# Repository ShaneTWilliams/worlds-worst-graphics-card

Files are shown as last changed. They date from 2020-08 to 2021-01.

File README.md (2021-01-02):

# World's Worst Graphics Card

This board consists of an SiI1136 HDMI transmitter, driven by a dual-core 480 MHz STM32H745IIT6 microcontroller, with 64 MB of external SDRAM. It is USB-powered and uses SWD for flash and debug.

The goal of this project is to give me a custom, bare-metal platform on which I can try my hand at implementing simple graphics algorithms from scratch. The STM32 is key for this, with its dual cores, DMA2D (a DMA peripheral designed to fill frame buffers very quickly) and its LTDC peripheral, which will drive the display without any CPU load.







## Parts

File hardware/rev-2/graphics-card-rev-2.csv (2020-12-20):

Id | Designator | Package | Quantity | Designation | Supplier and ref
1 | U6 | LQFP-176_24x24mm_P0.5mm | 1 | STM32H745IITx
2 | U5 | TQFP-100-1EP_14x14mm_P0.5mm_EP5x5mm | 1 | SiI1136
3 | CSCL | TestPoint_Pad_D1.0mm | 1 | CSCL
4 | CSDA | TestPoint_Pad_D1.0mm | 1 | CSDA
5 | C2,C13,C57,C58,C59,C60 | C_0805_2012Metric_Pad1.15x1.40mm_HandSolder | 6 | 4.7u
6 | C3,C4,C5,C6,C7,C8,C9,C10,C11,C12,C28,C29,C30,C31,C32,C33,C34,C35,C36,C37,C49,C51,C21,C23,C24,C25,C26,C27,C14,C15,C16,C17,C18,C19,C20,C38,C40,C41,C42,C43,C44,C46,C47,C55,C65,C66,C67,C63,C64 | C_0805_2012Metric_Pad1.15x1.40mm_HandSolder | 49 | 100n
7 | C1,C48,C50 | C_0805_2012Metric_Pad1.15x1.40mm_HandSolder | 3 | 1u
8 | C52,C53,C54 | C_0805_2012Metric_Pad1.15x1.40mm_HandSolder | 3 | 2.2u
9 | C22,C39,C45 | C_0805_2012Metric_Pad1.15x1.40mm_HandSolder | 3 | 10u
10 | C56 | C_0805_2012Metric_Pad1.15x1.40mm_HandSolder | 1 | 22u
11 | C61,C62 | C_0805_2012Metric_Pad1.15x1.40mm_HandSolder | 2 | 10p
12 | D1 | LED_0805_2012Metric_Pad1.15x1.40mm_HandSolder | 1 | 5V_LED
13 | D2 | LED_0805_2012Metric_Pad1.15x1.40mm_HandSolder | 1 | 3V3_LED
14 | D7 | LED_0805_2012Metric_Pad1.15x1.40mm_HandSolder | 1 | 1V2_LED
15 | D3 | LED_0805_2012Metric_Pad1.15x1.40mm_HandSolder | 1 | LED_IND0
16 | D4 | LED_0805_2012Metric_Pad1.15x1.40mm_HandSolder | 1 | LED_IND1
17 | D5 | LED_0805_2012Metric_Pad1.15x1.40mm_HandSolder | 1 | LED_IND2
18 | D6 | LED_0805_2012Metric_Pad1.15x1.40mm_HandSolder | 1 | LED_OK
19 | D8 | LED_0805_2012Metric_Pad1.15x1.40mm_HandSolder | 1 | LED_WARN
20 | D9 | LED_0805_2012Metric_Pad1.15x1.40mm_HandSolder | 1 | LED_ERR
21 | FB1,FB2,FB3 | R_0805_2012Metric_Pad1.15x1.40mm_HandSolder | 3 | 1k@100MHz
22 | J1,J2 | USB_Micro-B_Amphenol_10103594-0001LF_Horizontal | 2 | USB_B_Micro
23 | J3 | AMPHENOL_10029449-001RLF | 1 | HDMI_A
24 | L1 | L_0805_2012Metric_Pad1.15x1.40mm_HandSolder | 1 | 4.7u
25 | R1 | R_0805_2012Metric_Pad1.15x1.40mm_HandSolder | 1 | 510
26 | R2,R20,R19 | R_0805_2012Metric_Pad1.15x1.40mm_HandSolder | 3 | 10k
27 | R7,R15 | R_0805_2012Metric_Pad1.15x1.40mm_HandSolder | 2 | 330
28 | R3,R4,R6 | R_0805_2012Metric_Pad1.15x1.40mm_HandSolder | 3 | 4.7K
29 | R5 | R_0805_2012Metric_Pad1.15x1.40mm_HandSolder | 1 | 27k
30 | R8,R9 | R_0805_2012Metric_Pad1.15x1.40mm_HandSolder | 2 | 2k
31 | R10,R11,R12,R13,R14,R16 | R_0805_2012Metric_Pad1.15x1.40mm_HandSolder | 6 | 680
32 | R18 | R_0805_2012Metric_Pad1.15x1.40mm_HandSolder | 1 | 4.06k
33 | R17 | R_0805_2012Metric_Pad1.15x1.40mm_HandSolder | 1 | 400
34 | D+ | TestPoint_Pad_D1.0mm | 1 | USB_D+
35 | D- | TestPoint_Pad_D1.0mm | 1 | USB_D-
36 | +5 | TestPoint_Pad_D1.0mm | 1 | +5V
37 | VSYNC | TestPoint_Pad_D1.0mm | 1 | VSYNC
38 | +33 | TestPoint_Pad_D1.0mm | 1 | +3V3
39 | +12 | TestPoint_Pad_D1.0mm | 1 | +1V2
40 | CEC | TestPoint_Pad_D1.0mm | 1 | CEC
41 | DSCL | TestPoint_Pad_D1.0mm | 1 | DSCL
42 | DSDA | TestPoint_Pad_D1.0mm | 1 | DSDA
43 | HSYNC | TestPoint_Pad_D1.0mm | 1 | HSYNC
44 | IDCK | TestPoint_Pad_D1.0mm | 1 | IDCK
45 | DE | TestPoint_Pad_D1.0mm | 1 | DE
46 | U2 | SOT-23-5 | 1 | TPS613222ADBVR
47 | U3 | SOT-223-3_TabPin2 | 1 | ZLDO1117G33TA
48 | U1 | TSOP-II-54_22.2x10.16mm_P0.8mm | 1 | IS42S16400J-7TL
49 | U4 | SOT-223-3_TabPin2 | 1 | ZLDO1117G12TA
50 | Y1 | Crystal_SMD_5032-2Pin_5.0x3.2mm_HandSoldering | 1 | 40MHZ/8PF
51 | SW1,SW2 | PTS645SM43SMTR92_Switch | 2 | RESET
52 | J4 | PinHeader_2x03_P2.54mm_Vertical_SMD | 1 | Conn_02x03_Odd_Even
53 | +VIN | TestPoint_Pad_D1.0mm | 1 | USB_VIN
54 | Q1 | SOT-23 | 1 | ZXMN2A01F
55 | R21 | R_0805_2012Metric_Pad1.15x1.40mm_HandSolder | 1 | 100
56 | R22 | R_0805_2012Metric_Pad1.15x1.40mm_HandSolder | 1 | 1M

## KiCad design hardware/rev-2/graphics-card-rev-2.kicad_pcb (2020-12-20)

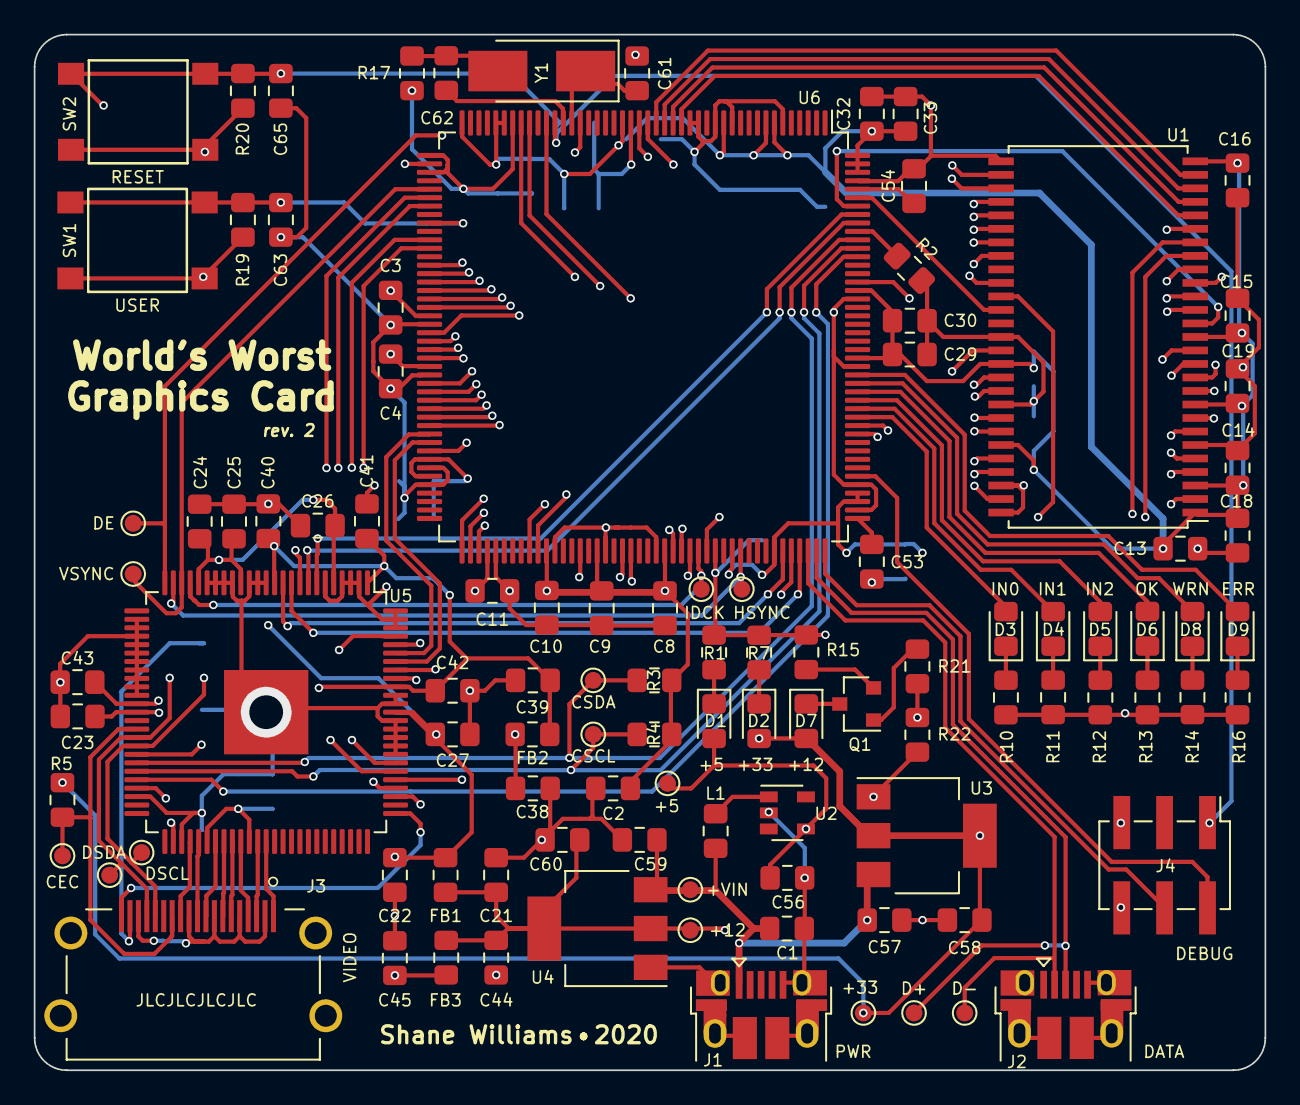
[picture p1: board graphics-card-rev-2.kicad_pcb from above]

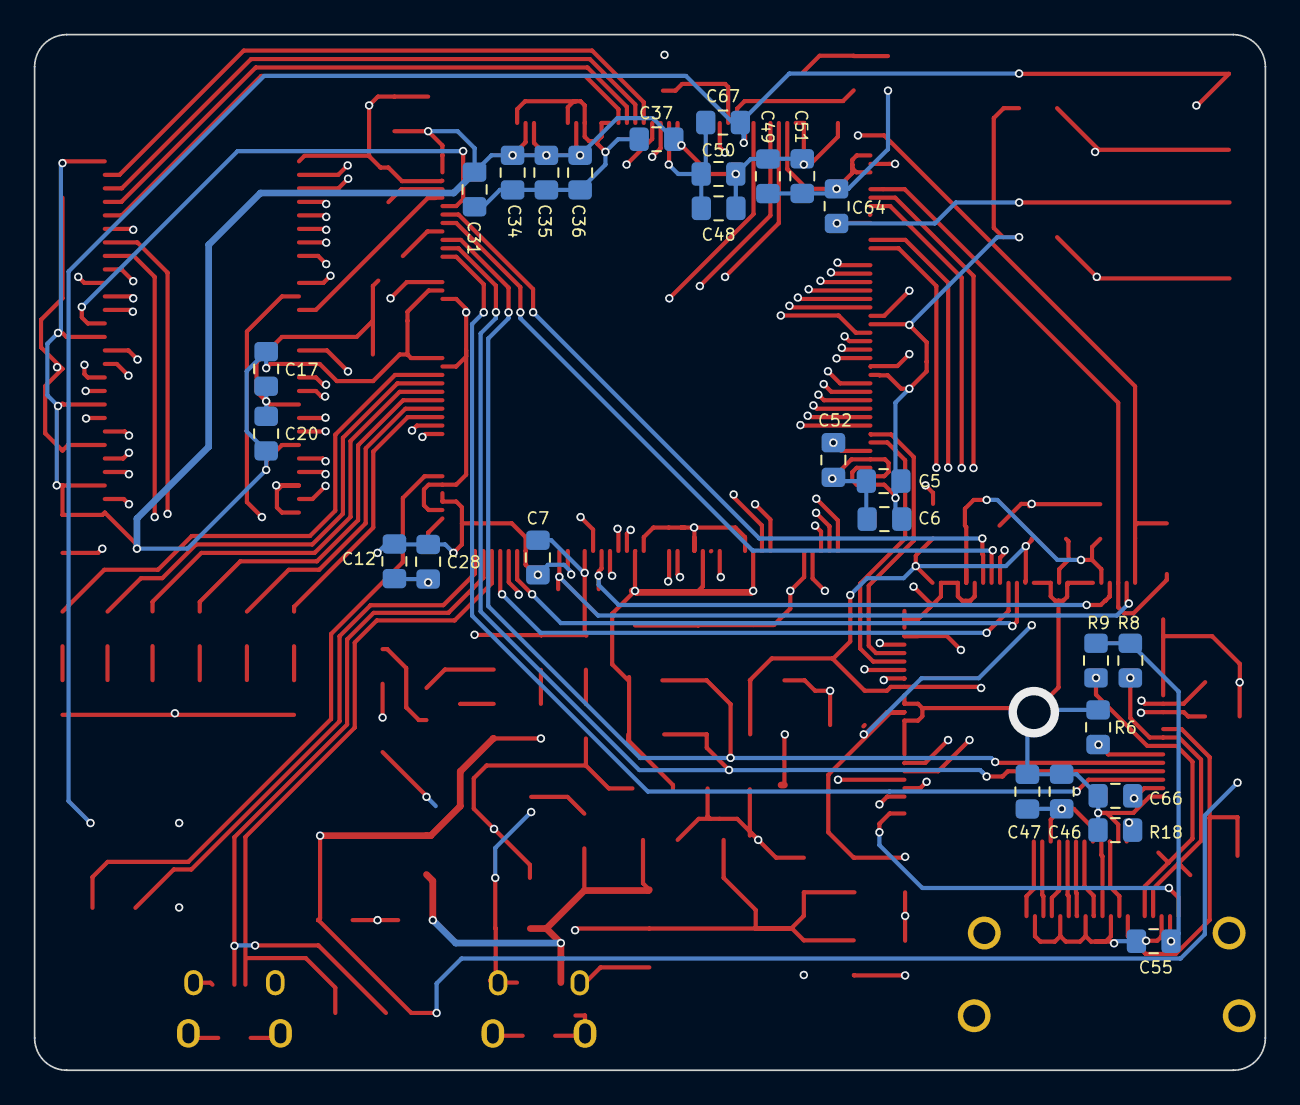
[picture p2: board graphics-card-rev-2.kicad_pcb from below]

Board: 4 copper layers, 72.9 x 61.3 mm, 131 parts (27 on the bottom side), 114 nets.

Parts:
+5: +5V; TestPoint_Pad_D1.0mm
+12: +1V2; TestPoint_Pad_D1.0mm
+33: +3V3; TestPoint_Pad_D1.0mm
+VIN: USB_VIN; TestPoint_Pad_D1.0mm
C1, C48, C50: 1u; C_0805_2012Metric_Pad1.15x1.40mm_HandSolder
C2, C13, C57, C58, C59, C60: 4.7u; C_0805_2012Metric_Pad1.15x1.40mm_HandSolder
C3, C4, C5, C6, C7, C8, C9, C10, C11, C12, C14, C15, C16, C17, C18, C19, C20, C21, C23, C24, C25, C26, C27, C28, C29, C30, C31, C32, C33, C34, C35, C36, C37, C38, C40, C41, C42, C43, C44, C46, C47, C49, C51, C55, C63, C64, C65, C66, C67: 100n; C_0805_2012Metric_Pad1.15x1.40mm_HandSolder
C22, C39, C45: 10u; C_0805_2012Metric_Pad1.15x1.40mm_HandSolder
C52, C53, C54: 2.2u; C_0805_2012Metric_Pad1.15x1.40mm_HandSolder
C56: 22u; C_0805_2012Metric_Pad1.15x1.40mm_HandSolder
C61, C62: 10p; C_0805_2012Metric_Pad1.15x1.40mm_HandSolder
CEC: CEC; TestPoint_Pad_D1.0mm
CSCL: CSCL; TestPoint_Pad_D1.0mm
CSDA: CSDA; TestPoint_Pad_D1.0mm
D1: 5V_LED; LED_0805_2012Metric_Pad1.15x1.40mm_HandSolder
D2: 3V3_LED; LED_0805_2012Metric_Pad1.15x1.40mm_HandSolder
D3: LED_IND0; LED_0805_2012Metric_Pad1.15x1.40mm_HandSolder
D4: LED_IND1; LED_0805_2012Metric_Pad1.15x1.40mm_HandSolder
D5: LED_IND2; LED_0805_2012Metric_Pad1.15x1.40mm_HandSolder
D6: LED_OK; LED_0805_2012Metric_Pad1.15x1.40mm_HandSolder
D7: 1V2_LED; LED_0805_2012Metric_Pad1.15x1.40mm_HandSolder
D8: LED_WARN; LED_0805_2012Metric_Pad1.15x1.40mm_HandSolder
D9: LED_ERR; LED_0805_2012Metric_Pad1.15x1.40mm_HandSolder
D+: USB_D+; TestPoint_Pad_D1.0mm
D-: USB_D-; TestPoint_Pad_D1.0mm
DE: DE; TestPoint_Pad_D1.0mm
DSCL: DSCL; TestPoint_Pad_D1.0mm
DSDA: DSDA; TestPoint_Pad_D1.0mm
FB1, FB2, FB3: 1k@100MHz; R_0805_2012Metric_Pad1.15x1.40mm_HandSolder
HSYNC: HSYNC; TestPoint_Pad_D1.0mm
IDCK: IDCK; TestPoint_Pad_D1.0mm
J1, J2: USB_B_Micro; USB_Micro-B_Amphenol_10103594-0001LF_Horizontal
J3: HDMI_A; AMPHENOL_10029449-001RLF
J4: Conn_02x03_Odd_Even; PinHeader_2x03_P2.54mm_Vertical_SMD
L1: 4.7u; L_0805_2012Metric_Pad1.15x1.40mm_HandSolder
Q1: ZXMN2A01F; SOT-23
R1: 510; R_0805_2012Metric_Pad1.15x1.40mm_HandSolder
R2, R19, R20: 10k; R_0805_2012Metric_Pad1.15x1.40mm_HandSolder
R3, R4, R6: 4.7K; R_0805_2012Metric_Pad1.15x1.40mm_HandSolder
R5: 27k; R_0805_2012Metric_Pad1.15x1.40mm_HandSolder
R7, R15: 330; R_0805_2012Metric_Pad1.15x1.40mm_HandSolder
R8, R9: 2k; R_0805_2012Metric_Pad1.15x1.40mm_HandSolder
R10, R11, R12, R13, R14, R16: 680; R_0805_2012Metric_Pad1.15x1.40mm_HandSolder
R17: 400; R_0805_2012Metric_Pad1.15x1.40mm_HandSolder
R18: 4.06k; R_0805_2012Metric_Pad1.15x1.40mm_HandSolder
R21: 100; R_0805_2012Metric_Pad1.15x1.40mm_HandSolder
R22: 1M; R_0805_2012Metric_Pad1.15x1.40mm_HandSolder
SW1, SW2: RESET; PTS645SM43SMTR92_Switch
U1: IS42S16400J-7TL; TSOP-II-54_22.2x10.16mm_P0.8mm
U2: TPS613222ADBVR; SOT-23-5
U3: ZLDO1117G33TA; SOT-223-3_TabPin2
U4: ZLDO1117G12TA; SOT-223-3_TabPin2
U5: SiI1136; TQFP-100-1EP_14x14mm_P0.5mm_EP5x5mm
U6: STM32H745IITx; LQFP-176_24x24mm_P0.5mm
VSYNC: VSYNC; TestPoint_Pad_D1.0mm
Y1: 40MHZ/8PF; Crystal_SMD_5032-2Pin_5.0x3.2mm_HandSoldering

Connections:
+1V2: +12.1, C21.1, C44.1, C60.1, FB1.2, FB3.2, R21.2, R22.1, U4.2
+3V3: +33.1, C2.1, C3.1, C4.1, C5.1, C6.1, C7.1, C8.1, C9.1, C10.1, C11.1, C12.1, C13.1, C14.1, C15.1, C16.1, C17.1, C18.1, C19.1, C20.1, C28.1, C29.1, C30.1, C31.1, C32.1, C33.1, C34.1, C35.1, C36.1, C37.1, C38.1, C48.1, C49.1, C50.1, C51.1, C58.1, D2.2, D7.2, FB2.2, R3.1, R4.1, R5.1, R19.1, R20.1, U1.1, U1.3, U1.9, U1.14, U1.27, U1.43, U1.49, U3.2, U6.7, U6.8, U6.13, U6.25, U6.39, U6.40, U6.44, U6.65, U6.71, U6.82, U6.84, U6.92, U6.99, U6.105, U6.113, U6.121, U6.126, U6.135, U6.136, U6.152, U6.160, U6.174, U6.175, U6.176
+5V: +5.1, C55.1, C56.1, D1.2, J3.18, R8.1, R9.1, U2.4
/AVCC_SII: C45.1, C46.1, C47.1, FB3.1, U5.56, U5.61
/B_CB_3: U5.11, U6.127
/B_CB_4: U5.10, U6.129
/B_CB_5: U5.9, U6.46
/B_CB_6: U5.8, U6.168
/B_CB_7: U5.7, U6.169
/CEC: CEC.1, J3.13, R5.2, U5.40
/CSCL: CSCL.1, R4.2, U5.45, U6.165
/CSDA: CSDA.1, R3.2, U5.44, U6.166
/CVCC12_SII: C22.1, C23.1, C24.1, C25.1, C26.1, C27.1, FB1.1, U5.5, U5.16, U5.21, U5.38, U5.88
/DE: DE.1, U5.25, U6.30
/DSCL: DSCL.1, J3.15, R9.2, U5.42
/DSDA: DSDA.1, J3.16, R8.2, U5.41
/G_Y_2: U5.97, U6.51
/G_Y_3: U5.96, U6.103
/G_Y_4: U5.95, U6.78
/G_Y_5: U5.94, U6.79
/G_Y_6: U5.93, U6.108
/G_Y_7: U5.92, U6.109
/HPD: J3.19, U5.76
/HSYNC: HSYNC.1, U5.24, U6.122
/IDCK: IDCK.1, U5.22, U6.117
/INT_SII: U5.46, U6.164
/IOVCC_SII: C39.1, C40.1, C41.1, C42.1, C43.1, FB2.1, U5.1, U5.12, U5.37, U5.91
/LED_ERR: D9.2, U6.150
/LED_IND0: D3.2, U6.145
/LED_IND1: D4.2, U6.146
/LED_IND2: D5.2, U6.147
/LED_OK: D6.2, U6.148
/LED_WARN: D8.2, U6.149
/OSC_IN: C61.1, U6.31, Y1.1
/OSC_OUT: R17.1, U6.32
/RAM_A0: U1.23, U6.18
/RAM_A1: U1.24, U6.19
/RAM_A2: U1.25, U6.20
/RAM_A3: U1.26, U6.21
/RAM_A4: U1.29, U6.22
/RAM_A5: U1.30, U6.23
/RAM_A6: U1.31, U6.59
/RAM_A7: U1.32, U6.60
/RAM_A8: U1.33, U6.61
/RAM_A9: U1.34, U6.62
/RAM_A10: U1.22, U6.63
/RAM_A11: U1.35, U6.66
/RAM_BA0: U1.20, U6.114
/RAM_BA1: U1.21, U6.115
/RAM_CKE: U1.37, U6.37
/RAM_CLK: U1.38, U6.118
/RAM_D0: U1.2, U6.97
/RAM_D1: U1.4, U6.98
/RAM_D2: U1.5, U6.143
/RAM_D3: U1.7, U6.144
/RAM_D4: U1.8, U6.67
/RAM_D5: U1.10, U6.68
/RAM_D6: U1.11, U6.69
/RAM_D7: U1.13, U6.72
/RAM_D8: U1.42, U6.73
/RAM_D9: U1.44, U6.74
/RAM_D10: U1.45, U6.75
/RAM_D11: U1.47, U6.76
/RAM_D12: U1.48, U6.77
/RAM_D13: U1.50, U6.89
/RAM_D14: U1.51, U6.90
/RAM_D15: U1.53, U6.91
/RAM_NBL0: U1.15, U6.170
/RAM_NBL1: U1.39, U6.171
/R_CR_3: U5.82, U6.55
/R_CR_4: U5.81, U6.50
/R_CR_5: U5.80, U6.128
/R_CR_6: U5.79, U6.56
/R_CR_7: U5.78, U6.116
/SWCLK: J4.2, U6.138
/SWDIO: J4.4, U6.132
/TMDS_CLK+: J3.10, U5.55
/TMDS_CLK-: J3.12, U5.54
/TMDS_D0+: J3.7, U5.58
/TMDS_D0-: J3.9, U5.57
/TMDS_D1+: J3.4, U5.60
/TMDS_D1-: J3.6, U5.59
/TMDS_D2+: J3.1, U5.63
/TMDS_D2-: J3.3, U5.62
/USB_D+: D+.1, J2.3, U6.131
/USB_D-: D-.1, J2.2, U6.130
/USB_VIN: +VIN.1, C1.1, C57.1, C59.1, J1.1, L1.1, U3.3, U4.3
/VSYNC: U5.23, U6.49, VSYNC.1
/~RAM_CAS: U1.17, U6.161
/~RAM_CS: U1.19, U6.36
/~RAM_RAS: U1.18, U6.58
/~RAM_WE: U1.16, U6.34
/~RESET: C65.1, C66.1, C67.1, J4.1, R20.2, SW2.1, U5.47, U6.33
/~USR_BTN: C63.1, C64.1, R19.2, SW1.1, U6.53
GND: C1.2, C2.2, C3.2, C4.2, C5.2, C6.2, C7.2, C8.2, C9.2, C10.2, C11.2, C12.2, C13.2, C14.2, C15.2, C16.2, C17.2, C18.2, C19.2, C20.2, C21.2, C22.2, C23.2, C24.2, C25.2, C26.2, C27.2, C28.2, C29.2, C30.2, C31.2, C32.2, C33.2, C34.2, C35.2, C36.2, C37.2, C38.2, C39.2, C40.2, C41.2, C42.2, C43.2, C44.2, C45.2, C46.2, C47.2, C48.2, C49.2, C50.2, C51.2, C52.2, C53.2, C54.2, C55.2, C56.2, C57.2, C58.2, C59.2, C60.2, C61.2, C62.2, C63.2, C64.2, C65.2, C66.2, C67.2, J1.5, J1.6, J2.5, J2.6, J3.2, J3.5, J3.8, J3.11, J3.17, J3.SH, J4.5, J4.6, R1.2, R2.2, R6.2, R7.2, R10.1, R11.1, R12.1, R13.1, R14.1, R15.2, R16.1, R18.2, R22.2, SW1.2, SW2.2, U1.6, U1.12, U1.28, U1.41, U1.46, U1.52, U1.54, U2.2, U3.1, U4.1, U5.2, U5.3, U5.4, U5.6, U5.13, U5.14, U5.15, U5.17, U5.18, U5.19, U5.20, U5.27, U5.28, U5.29, U5.30, U5.31, U5.32, U5.33, U5.34, U5.35, U5.36, U5.48, U5.53, U5.83, U5.84, U5.85, U5.86, U5.87, U5.89, U5.90, U5.98, U5.99, U5.100, U5.101, U6.6, U6.12, U6.14, U6.16, U6.17, U6.24, U6.38, U6.45, U6.47, U6.64, U6.70, U6.81, U6.83, U6.93, U6.100, U6.106, U6.112, U6.119, U6.134, U6.137, U6.151, U6.159, U6.173
unnamed: C52.1, U6.80
unnamed: C53.1, U6.133
unnamed: C54.1, U6.172
unnamed: C62.1, R17.2, Y1.2
unnamed: D1.1, R1.1
unnamed: D2.1, R7.1
unnamed: D3.1, R10.2
unnamed: D4.1, R11.2
unnamed: D5.1, R12.2
unnamed: D6.1, R13.2
unnamed: D7.1, Q1.3
unnamed: D8.1, R14.2
unnamed: D9.1, R16.2
unnamed: L1.2, U2.1
unnamed: Q1.1, R21.1
unnamed: Q1.2, R15.1
unnamed: R2.1, U6.167
unnamed: R6.1, U5.43
unnamed: R18.1, U5.52

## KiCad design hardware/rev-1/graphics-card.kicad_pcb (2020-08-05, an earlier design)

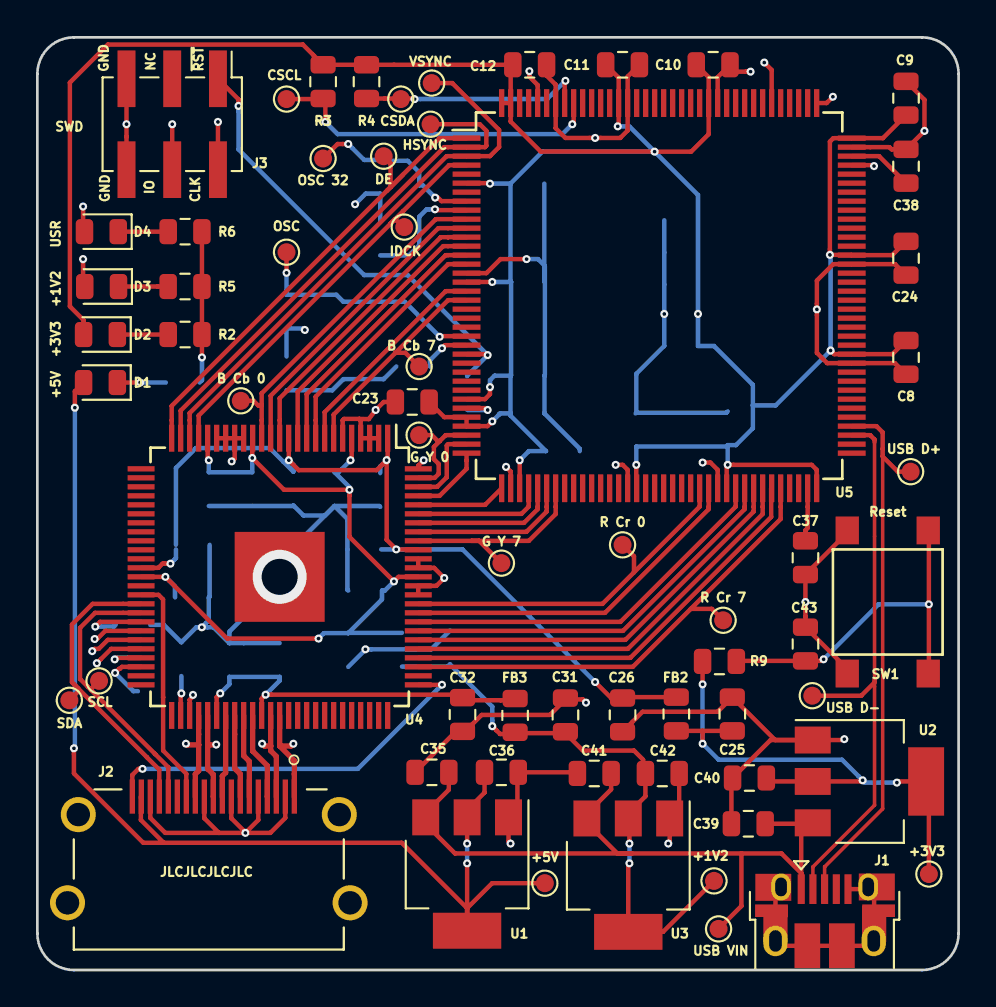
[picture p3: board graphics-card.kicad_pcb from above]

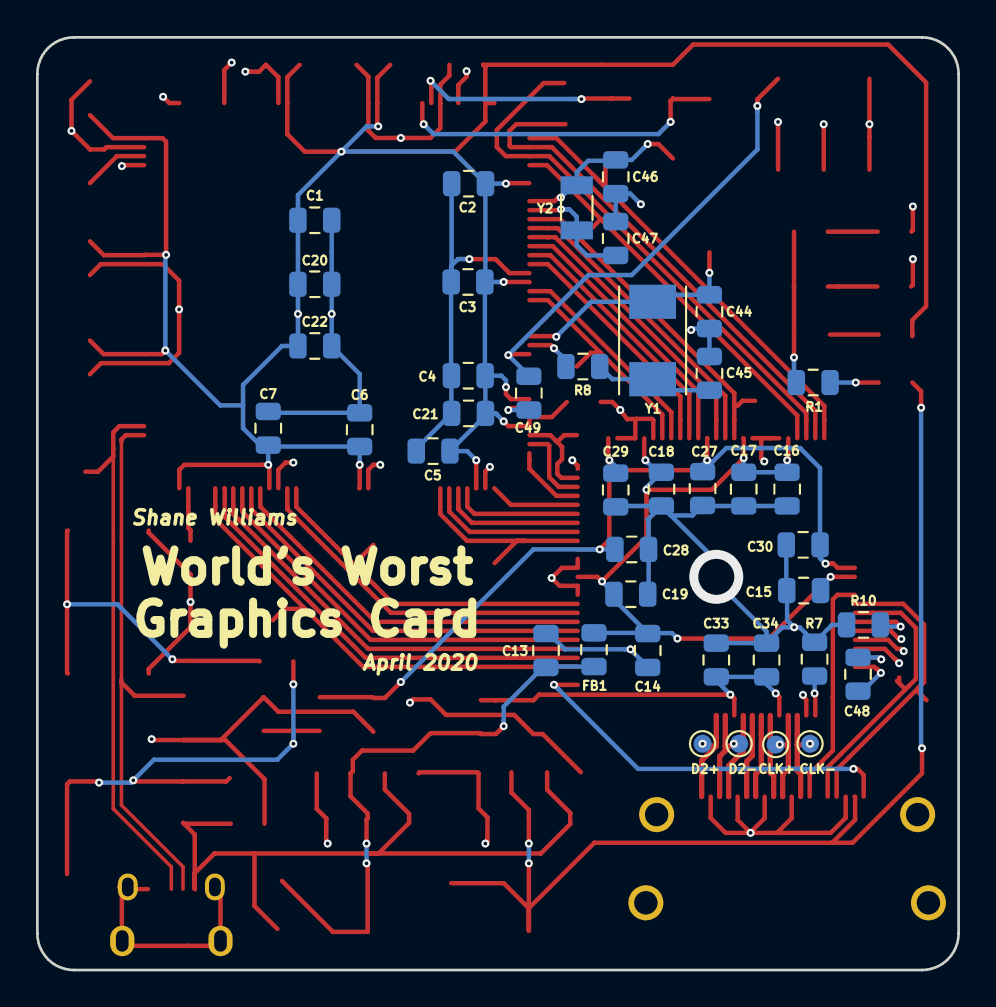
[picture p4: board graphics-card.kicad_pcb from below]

Board: 4 copper layers, 51.2 x 51.8 mm, 103 parts (40 on the bottom side), 70 nets.

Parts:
+1V2: +1V2; TestPoint_Pad_D1.0mm
+3V3: +3V3; TestPoint_Pad_D1.0mm
+5V: +5V; TestPoint_Pad_D1.0mm
B Cb 0: B_CB_0; TestPoint_Pad_D1.0mm
B Cb 7: B_CB_7; TestPoint_Pad_D1.0mm
C1: 4.7u; C_0805_2012Metric
C2, C3, C4, C5, C6, C7, C8, C9, C10, C11, C12, C13, C15, C16, C17, C18, C19, C21, C23, C24, C25, C27, C28, C29, C30, C31, C33, C34, C37, C38, C43, C48, C49: 100n; C_0805_2012Metric
C14, C26, C32: 10u; C_0805_2012Metric
C20, C22, C35, C36, C39, C40, C41, C42: 1u; C_0805_2012Metric
C44, C45: 27p; C_0805_2012Metric
C46, C47: 15p; C_0805_2012Metric
CLK+: CLK+; TestPoint_Pad_D1.0mm
CLK-: CLK-; TestPoint_Pad_D1.0mm
CSCL: CSCL; TestPoint_Pad_D1.0mm
CSDA: CSDA; TestPoint_Pad_D1.0mm
D1: 5V Rail LED; LED_0805_2012Metric
D2: 3.3V Rail LED; LED_0805_2012Metric
D2+: D2+; TestPoint_Pad_D1.0mm
D2-: D2-; TestPoint_Pad_D1.0mm
D3: 1.2V Rail LED; LED_0805_2012Metric
D4: USR_LED; LED_0805_2012Metric
DE: DE; TestPoint_Pad_D1.0mm
FB1, FB2, FB3: 1k@100MHz; R_0805_2012Metric
G Y 0: G_Y_0; TestPoint_Pad_D1.0mm
G Y 7: G_Y_7; TestPoint_Pad_D1.0mm
HSYNC: HSYNC; TestPoint_Pad_D1.0mm
IDCK: IDCK; TestPoint_Pad_D1.0mm
J1: USB_B_Micro; USB_Micro-B_Amphenol_10103594-0001LF_Horizontal
J2: HDMI_A_1.4; AMPHENOL_10029449-001RLF
J3: Conn_02x03_Odd_Even; PinHeader_2x03_P2.54mm_Vertical_SMD
OSC: OSC_IN; TestPoint_Pad_D1.0mm
OSC 32: OSC32_IN; TestPoint_Pad_D1.0mm
R1: 510; R_0805_2012Metric
R2: 330; R_0805_2012Metric
R3, R4, R10: 4.7k; R_0805_2012Metric
R5: 120; R_0805_2012Metric
R6: 680; R_0805_2012Metric
R7: 4.06k; R_0805_2012Metric
R8: 240; R_0805_2012Metric
R9: 10k; R_0805_2012Metric
R Cr 0: R_CR_0; TestPoint_Pad_D1.0mm
R Cr 7: R_CR_7; TestPoint_Pad_D1.0mm
SCL: SCL; TestPoint_Pad_D1.0mm
SDA: SDA; TestPoint_Pad_D1.0mm
SW1: Push Switch; PTS645SM43SMTR92_Switch
U1: AZ1117-5.0; SOT-223-3_TabPin2
U2: AZ1117-3.3; SOT-223-3_TabPin2
U3: AZ1117-1.2; SOT-223-3_TabPin2
U4: SiI1136; TQFP-100-1EP_14x14mm_P0.5mm_EP5x5mm
U5: STM32H753ZITx; LQFP-144_20x20mm_P0.5mm
USB D+: USB1_D+; TestPoint_Pad_D1.0mm
USB D-: USB1_D-; TestPoint_Pad_D1.0mm
USB VIN: USB_VIN; TestPoint_Pad_D1.0mm
VSYNC: VSYNC; TestPoint_Pad_D1.0mm
Y1: OSC; Crystal_SMD_Abracon_ABM7-2Pin_6.0x3.5mm
Y2: OSC_32; Crystal_SMD_3215-2Pin_3.2x1.5mm

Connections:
+1V2: +1V2.1, C13.1, C31.1, C42.1, D3.2, FB1.2, FB3.2, U3.2
+3V3: +3V3.1, C1.1, C2.1, C3.1, C4.1, C5.1, C6.1, C7.1, C8.1, C9.1, C10.1, C11.1, C12.1, C20.1, C21.1, C22.1, C23.1, C24.1, C25.1, C40.1, D2.2, FB2.2, R3.1, R4.1, R9.1, U2.2, U5.6, U5.17, U5.30, U5.32, U5.33, U5.39, U5.52, U5.62, U5.72, U5.84, U5.95, U5.108, U5.121, U5.131, U5.143, U5.144
+5V: +5V.1, C36.1, D1.2, J2.18, U1.2
/AVCC_SII: C32.1, C33.1, C34.1, FB3.1, U4.56, U4.61
/B_CB_0: B Cb 0.1, U4.15, U5.10
/B_CB_1: U4.14, U5.11
/B_CB_2: U4.13, U5.12
/B_CB_3: U4.11, U5.13
/B_CB_4: U4.10, U5.14
/B_CB_5: U4.9, U5.15
/B_CB_6: U4.8, U5.18
/B_CB_7: B Cb 7.1, U4.7, U5.19
/CEC: J2.13, U4.40
/CI2CA: R10.2, U4.43
/CLK+: CLK+.1, J2.10, U4.55
/CLK-: CLK-.1, J2.12, U4.54
/CSCL: CSCL.1, R3.2, U4.45, U5.136
/CSDA: CSDA.1, R4.2, U4.44, U5.137
/CVCC12_SII: C14.1, C15.1, C16.1, C17.1, C18.1, C19.1, FB1.1, U4.5, U4.16, U4.21, U4.38, U4.88
/D0+: J2.7, U4.58
/D0-: J2.9, U4.57
/D1+: J2.4, U4.60
/D1-: J2.6, U4.59
/D2+: D2+.1, J2.1, U4.63
/D2-: D2-.1, J2.3, U4.62
/DE: DE.1, U4.25, U5.1
/G_Y_0: G Y 0.1, U4.99, U5.34
/G_Y_1: U4.98, U5.35
/G_Y_2: U4.97, U5.36
/G_Y_3: U4.96, U5.37
/G_Y_4: U4.95, U5.40
/G_Y_5: U4.94, U5.41
/G_Y_6: U4.93, U5.42
/G_Y_7: G Y 7.1, U4.92, U5.43
/HPD: J2.19, U4.76
/HSYNC: HSYNC.1, U4.24, U5.2
/IDCK: IDCK.1, U4.22, U5.4
/INT_SII: U4.46, U5.140
/IOVCC_SII: C26.1, C27.1, C28.1, C29.1, C30.1, FB2.1, U4.1, U4.12, U4.37, U4.91
/OSC32_IN: C46.1, OSC 32.1, U5.8, Y2.1
/OSC32_OUT: C47.1, U5.9, Y2.2
/OSC_IN: C44.1, OSC.1, U5.23, Y1.1
/OSC_OUT: R8.2, U5.24
/R_CR_0: R Cr 0.1, U4.85, U5.59
/R_CR_1: U4.84, U5.60
/R_CR_2: U4.83, U5.63
/R_CR_3: U4.82, U5.64
/R_CR_4: U4.81, U5.65
/R_CR_5: U4.80, U5.66
/R_CR_6: U4.79, U5.67
/R_CR_7: R Cr 7.1, U4.78, U5.68
/SCL: J2.15, SCL.1, U4.42
/SDA: J2.16, SDA.1, U4.41
/SWCLK: J3.2, U5.109
/SWDIO: J3.4, U5.105
/USB1_D+: J1.3, U5.76, USB D+.1
/USB1_D-: J1.2, U5.75, USB D-.1
/USB_VIN: C35.1, C39.1, C41.1, J1.1, U1.3, U2.3, U3.3, USB VIN.1
/VSYNC: U4.23, U5.3, VSYNC.1
/~RESET: C43.1, C48.1, C49.1, J3.1, R9.2, SW1.2, U4.47, U5.25
GND: C1.2, C2.2, C3.2, C4.2, C5.2, C6.2, C7.2, C8.2, C9.2, C10.2, C11.2, C12.2, C13.2, C14.2, C15.2, C16.2, C17.2, C18.2, C19.2, C20.2, C21.2, C22.2, C23.2, C24.2, C25.2, C26.2, C27.2, C28.2, C29.2, C30.2, C31.2, C32.2, C33.2, C34.2, C35.2, C36.2, C37.2, C38.2, C39.2, C40.2, C41.2, C42.2, C43.2, C44.2, C45.2, C46.2, C47.2, C48.2, C49.2, J1.5, J1.6, J2.2, J2.5, J2.8, J2.11, J2.17, J2.SH, J3.5, J3.6, R1.2, R2.2, R5.2, R6.1, R7.2, R10.1, SW1.1, U1.1, U2.1, U3.1, U4.2, U4.3, U4.4, U4.6, U4.17, U4.18, U4.19, U4.20, U4.48, U4.53, U4.86, U4.87, U4.89, U4.90, U4.100, U4.101, U5.16, U5.31, U5.38, U5.51, U5.61, U5.83, U5.94, U5.107, U5.120, U5.130, U5.138
unnamed: C37.1, U5.71
unnamed: C38.1, U5.106
unnamed: C45.1, R8.1, Y1.2
unnamed: D1.1, R1.1
unnamed: D2.1, R2.1
unnamed: D3.1, R5.1
unnamed: D4.1, R6.2
unnamed: D4.2, U5.114
unnamed: R7.1, U4.52

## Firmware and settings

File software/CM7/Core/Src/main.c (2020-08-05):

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
/* Includes ------------------------------------------------------------------*/
#include "main.h"

/* USER CODE BEGIN PD */

#define HSEM_ID_0 (0U) /* HW semaphore 0*/
/* USER CODE END PD */


void SystemClock_Config(void);
/**
  * @brief  The application entry point.
  * @retval int
  */
int main(void)
{
/* USER CODE BEGIN Boot_Mode_Sequence_0 */
  int32_t timeout;
/* USER CODE END Boot_Mode_Sequence_0 */

/* USER CODE BEGIN Boot_Mode_Sequence_1 */
  /* Wait until CPU2 boots and enters in stop mode or timeout*/
  timeout = 0xFFFF;
  while((__HAL_RCC_GET_FLAG(RCC_FLAG_D2CKRDY) != RESET) && (timeout-- > 0));
  if ( timeout < 0 )
  {
  Error_Handler();
  }
/* USER CODE END Boot_Mode_Sequence_1 */
  /* MCU Configuration--------------------------------------------------------*/

  /* Reset of all peripherals, Initializes the Flash interface and the Systick. */
  HAL_Init();

  /* Configure the system clock */
  SystemClock_Config();
/* USER CODE BEGIN Boot_Mode_Sequence_2 */
/* When system initialization is finished, Cortex-M7 will release Cortex-M4 by means of
HSEM notification */
/*HW semaphore Clock enable*/
__HAL_RCC_HSEM_CLK_ENABLE();
/*Take HSEM */
HAL_HSEM_FastTake(HSEM_ID_0);
/*Release HSEM in order to notify the CPU2(CM4)*/
HAL_HSEM_Release(HSEM_ID_0,0);
/* wait until CPU2 wakes up from stop mode */
timeout = 0xFFFF;
while((__HAL_RCC_GET_FLAG(RCC_FLAG_D2CKRDY) == RESET) && (timeout-- > 0));
if ( timeout < 0 )
{
Error_Handler();
}
/* USER CODE END Boot_Mode_Sequence_2 */

  /* Initialize all configured peripherals */
  /* Infinite loop */
  /* USER CODE BEGIN WHILE */
  while (1)
  {
    /* USER CODE END WHILE */

    /* USER CODE BEGIN 3 */
  }
  /* USER CODE END 3 */
}

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


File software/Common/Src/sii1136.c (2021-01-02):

#include "sii1136.h"

// I2C Statuses.
typedef enum {
	SII1136_I2C_STATUS_OK = 0x00,
	SII1136_I2C_STATUS_ERROR = 0x01,
	SII1136_I2C_STATUS_BUSY = 0x02,
	SII1136_I2C_STATUS_TIMEOUT = 0x03
} sii1136_i2c_status_t;

// SiI1136 Register Addresses.
enum {
	SII1136_REG_PXL_CLK_LSB = 0x00,
	SII1136_REG_PXL_CLK_MSB = 0x01,
	SII1136_REG_VFREQ_LSB = 0x02,
	SII1136_REG_VFREQ_MSB = 0x03,
	SII1136_REG_HORIZ_RES_LSB = 0x04,
	SII1136_REG_HORIZ_RES_MSB = 0x05,
	SII1136_REG_VERT_RES_LSB = 0x06,
	SII1136_REG_VERT_RES_MSB = 0x07,

	SII1136_REG_IN_VID_FMT = 0x08,
	SII1136_REG_IN_COLOR_FMT = 0x09,
	SII1136_REG_OUT_COLOR_FMT = 0x0A,
	SII1136_REG_YC_IN_FMT = 0x0B,

	SII1136_REG_SYS_CNTL = 0x1A,

	SII1136_REG_DEV_ID = 0x1B,
	SII1136_REG_DEV_REV_ID = 0x1C,
	SII1136_REG_TPI_REV = 0x1D,

	SII1136_REG_INT_EN = 0x3C,
	SII1136_REG_INT_STATUS = 0x3D,

	SII1136_REG_SYNC_GEN = 0x60,
	SII1136_REG_SYNC_DET = 0x61,

	SII1136_REG_DE_DLY_LSB = 0x62,
	SII1136_REG_DE_DLY_MSB = 0x63,
	SII1136_REG_DE_GEN_FLAGS = 0x63,
	SII1136_REG_DE_TOP = 0x64,
	SII1136_REG_DE_CNT_LSB = 0x66,
	SII1136_REG_DE_CNT_MSB = 0x67,
	SII1136_REG_DE_LIN_LSB = 0x68,
	SII1136_REG_DE_LIN_MSB = 0x69,
	SII1136_REG_H_RES_LSB = 0x6A,
	SII1136_REG_H_RES_MSB = 0x6B,
	SII1136_REG_V_RES_LSB = 0x6C,
	SII1136_REG_V_RES_MSB = 0x6D,

	SII1136_REG_HBIT_LSB = 0x62,
	SII1136_REG_HBIT_MSB = 0x63,
	SII1136_REG_EMB_SYNC_EN = 0x63,
	SII1136_REG_F2_OFST_LSB = 0x64,
	SII1136_REG_F2_OFST_MSB = 0x65,
	SII1136_REG_HWIDTH_LSB = 0x66,
	SII1136_REG_HWIDTH_MSB = 0x67,
	SII1136_REG_VBIT = 0x68,
	SII1136_REG_VWIDTH = 0x69,

	SII1136_REG_TPI_INIT = 0xC7
};

/********************************
 ***** I2C HELPER FUNCTIONS *****
 ********************************/

static inline sii1136_i2c_status_t sii1136_i2c_write_reg(sii1136_t* self, uint16_t mem_addr,
															uint8_t data) {
	HAL_StatusTypeDef status = HAL_I2C_Mem_Write(self->_i2c_handle, self->_i2c_addr, mem_addr, 1,
			&data, 1, self->_i2c_timeout);
	return (sii1136_i2c_status_t)status;
}

static inline sii1136_i2c_status_t sii1136_i2c_write_multi_reg(sii1136_t* self, uint16_t mem_addr,
																uint8_t* data, size_t size_b) {
	HAL_StatusTypeDef status = HAL_I2C_Mem_Write(self->_i2c_handle, self->_i2c_addr, mem_addr, 1,
			data, size_b, self->_i2c_timeout);
	return (sii1136_i2c_status_t)status;
}

static inline sii1136_i2c_status_t sii1136_i2c_read_reg(sii1136_t* self, uint16_t mem_addr,
														uint8_t* data) {
	HAL_StatusTypeDef status = HAL_I2C_Mem_Read(self->_i2c_handle, self->_i2c_addr, mem_addr, 1,
			data, 1, self->_i2c_timeout);
	return (sii1136_i2c_status_t)status;
}

static inline sii1136_i2c_status_t sii1136_i2c_read_multi_reg(sii1136_t* self, uint16_t mem_addr,
																uint8_t* data, size_t size_b) {
	HAL_StatusTypeDef status = HAL_I2C_Mem_Read(self->_i2c_handle, self->_i2c_addr, mem_addr, 1,
			data, size_b, self->_i2c_timeout);
	return (sii1136_i2c_status_t)status;
}

/****************************************
 ***** TPI INITIALIZATION FUNCTIONS *****
 ****************************************/

void sii1136_configure_i2c(sii1136_t* self, I2C_HandleTypeDef* i2c, uint8_t i2c_timeout,
							uint8_t i2c_addr) {
	self->_i2c_handle = i2c;
	self->_i2c_timeout = i2c_timeout;
	self->_i2c_addr = i2c_addr;
}

sii1136_status_t sii1136_init_tpi(sii1136_t* self) {
	sii1136_i2c_status_t status = sii1136_i2c_write_reg(self, SII1136_REG_TPI_INIT, 0x00);
	if (status == SII1136_I2C_STATUS_OK) {
		return SII1136_STATUS_OK;
	}
	return SII1136_STATUS_I2C_ERR;
}

sii1136_status_t sii1136_tpi_ready(sii1136_t* self, sii1136_tpi_status_t* tpi_status) {
	if (self->_i2c_handle->State != HAL_I2C_STATE_READY) {
		*tpi_status = SII1136_TPI_STATUS_I2C_ERR;
		return SII1136_STATUS_OK;
	}
	uint8_t device_id = 0x00;
	sii1136_i2c_status_t i2c_status = sii1136_i2c_read_reg(self, SII1136_REG_DEV_ID, &device_id);
	if (i2c_status != SII1136_I2C_STATUS_OK) {
		*tpi_status = SII1136_TPI_STATUS_I2C_ERR;
		return SII1136_STATUS_I2C_ERR;
	} else if (device_id != 0xB0) {
		*tpi_status = SII1136_TPI_STATUS_BAD_ID;
		return SII1136_STATUS_OK;
	}
	*tpi_status = SII1136_TPI_STATUS_READY;
	return SII1136_STATUS_OK;
}

/********************************************
 ***** REGISTER GETTER/SETTER FUNCTIONS *****
 ********************************************/

/***** IDENTIFICATION REGISTERS *****/

sii1136_status_t sii1136_get_device_id(sii1136_t* self, uint8_t* device_id) {
	if (self == NULL) {
		return SII1136_STATUS_NULL_ARG;
	}
	sii1136_i2c_status_t i2c_status = sii1136_i2c_read_reg(self, SII1136_REG_DEV_ID, device_id);
	return i2c_status == SII1136_I2C_STATUS_OK ? SII1136_STATUS_OK : SII1136_STATUS_I2C_ERR;
}

sii1136_status_t sii1136_get_device_rev_id(sii1136_t* self, uint8_t* device_rev_id) {
	if (self == NULL) {
		return SII1136_STATUS_NULL_ARG;
	}
	sii1136_i2c_status_t i2c_status = sii1136_i2c_read_reg(self, SII1136_REG_DEV_REV_ID,
			device_rev_id);
	return i2c_status == SII1136_I2C_STATUS_OK ? SII1136_STATUS_OK : SII1136_STATUS_I2C_ERR;
}

sii1136_status_t sii1136_get_tpi_rev(sii1136_t* self, uint8_t* tpi_revision) {
	if (self == NULL) {
		return SII1136_STATUS_NULL_ARG;
	}
	sii1136_i2c_status_t i2c_status = sii1136_i2c_read_reg(self, SII1136_REG_TPI_REV, tpi_revision);
	return i2c_status == SII1136_I2C_STATUS_OK ? SII1136_STATUS_OK : SII1136_STATUS_I2C_ERR;
}

sii1136_status_t sii1136_set_device_id(sii1136_t* self, uint8_t device_id) {
	if (self == NULL) {
		return SII1136_STATUS_NULL_ARG;
	}
	sii1136_i2c_status_t i2c_status = sii1136_i2c_write_reg(self, SII1136_REG_DEV_ID, device_id);
	return i2c_status == SII1136_I2C_STATUS_OK ? SII1136_STATUS_OK : SII1136_STATUS_I2C_ERR;
}

sii1136_status_t sii1136_set_device_rev_id(sii1136_t* self, uint8_t device_rev_id) {
	if (self == NULL) {
		return SII1136_STATUS_NULL_ARG;
	}
	sii1136_i2c_status_t i2c_status = sii1136_i2c_write_reg(self, SII1136_REG_DEV_REV_ID,
			device_rev_id);
	return i2c_status == SII1136_I2C_STATUS_OK ? SII1136_STATUS_OK : SII1136_STATUS_I2C_ERR;
}

sii1136_status_t sii1136_set_tpi_rev(sii1136_t* self, uint8_t tpi_revision) {
	if (self == NULL) {
		return SII1136_STATUS_NULL_ARG;
	}
	sii1136_i2c_status_t i2c_status = sii1136_i2c_write_reg(self, SII1136_REG_TPI_REV,
			tpi_revision);
	return i2c_status == SII1136_I2C_STATUS_OK ? SII1136_STATUS_OK : SII1136_STATUS_I2C_ERR;
}

/***** INPUT FORMAT REGISTERS *****/

sii1136_status_t sii1136_get_pixel_clock(sii1136_t* self, uint32_t* pixel_clock) {
	if (self == NULL) {
		return SII1136_STATUS_NULL_ARG;
	}
	sii1136_i2c_status_t i2c_status = sii1136_i2c_read_multi_reg(self, SII1136_REG_PXL_CLK_LSB,
			(uint8_t*)pixel_clock, 2);
	*pixel_clock *= 10000;
	return i2c_status == SII1136_I2C_STATUS_OK ? SII1136_STATUS_OK : SII1136_STATUS_I2C_ERR;
}
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

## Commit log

2020-08-05 feat: Add first revision hardware files
    [BOM.csv, _saved_graphics-card.sch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]
2020-08-05 feat: Add STM32CubeIDE project with boilerplate HAL code
2020-12-20 feat: Add second revision hardware files
    [_saved_graphics-card-rev-2.sch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]
2021-01-02 [WIP] feat: Add SiI1136 driver

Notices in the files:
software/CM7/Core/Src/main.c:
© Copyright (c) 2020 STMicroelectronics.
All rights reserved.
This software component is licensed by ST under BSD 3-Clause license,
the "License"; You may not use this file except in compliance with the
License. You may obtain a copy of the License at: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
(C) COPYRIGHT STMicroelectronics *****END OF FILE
